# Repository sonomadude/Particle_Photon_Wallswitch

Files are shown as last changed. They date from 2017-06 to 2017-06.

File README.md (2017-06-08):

# Particle_Photon_Wallswitch
This repository will hold all assets for my entry into the Hackaday prize 2017 - a Particle Photon WallSwitch.

The goal of this project is to create a wall switch assembly that can fit into a deep US junction box, and, since it is using mains power directly, to do this safely (I will be installing a number of these in my barn, and eventually home if all goes well, so it has to be safe). And the switch must be both locally and remotely controllable.

On the safety end, great care is being taken in PCB layout to insure safe and reliable operation. The Saturn PCB Design Toolkit and PCB layout DRC (Design Rule Checking) was used to make sure trace separations met requirements for safety.  Board slots were also cut underneath the flyback transformer and the relay, separating the mains or 170VDC PCB areas from the nearby 5VDC areas. The assembly includes a fused resistor at power entry (that hopefully never blows because it cannot be reset) in case of a catastrophic failure of the 120VAC to 5VDC circuitry. All ingress wires are clamped to the PCB board for strain relief. If there is time, a probably oversimplified and probably crude EMC pre-compliance test will be done in my lab. 

There will be 5 ways to control the switch.  The first, physically making it switch, is done via a capacitive touch button. That button can be off or illuminated dimly when the switch is off, and then illuminated brightly when the switch is on (brightness controlled via PWM). To control the light remotely, an Android app, an iPhone app, an Alexa skill, and a web page will be created.

The firmware in the Particle Photon will initially just be able to turn on and off the switch. In final form, that firmware will be able to programmatically turn the switch on and off, either through specified times, or based on sunset or sunrise. The firmware will include the ability to identify time zone, DST, and sunrise/sunset using the Particle Cloud’s Webhooks capability.

The remote app software will also initially just be for turn on and turn off. But the finished apps will be able to set the time-based scheduling methods mentioned in the firmware paragraph above.  In addition, they will also be able to arrange multiple light switches into groups, and control those groups in the same manner – on/off, scheduled times, times based on sunrise/sunset.  A status display showing each of the lights is hoped to be part of this project.

If possible and not too over-ambitious, detailed documentation and videos will be created. 

I doubt there will be time but in an ideal world, a comparison of the cost to manufacture this unit in volume in China versus in the US in my lab would be great!  As currently designed and spec’d, this unit, if a real-world product, would be a complete fail - it is just too costly to make in the US.

I am hoping the ongoing project summary and the depth of the documentation will be of use to fellow developers and makers.  All IP of the project will be open source.

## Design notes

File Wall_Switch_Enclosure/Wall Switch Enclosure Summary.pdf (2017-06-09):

# Wall Switch Enclosure Summary

### (designed using Autodesk Inventor)

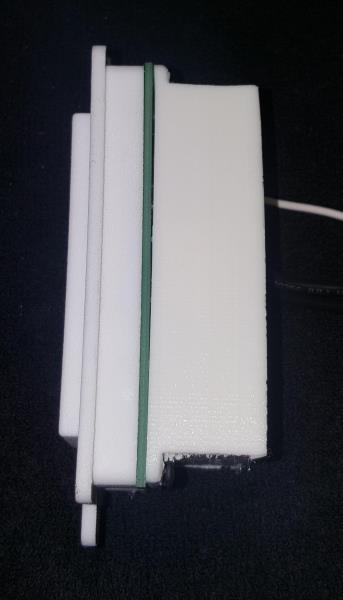
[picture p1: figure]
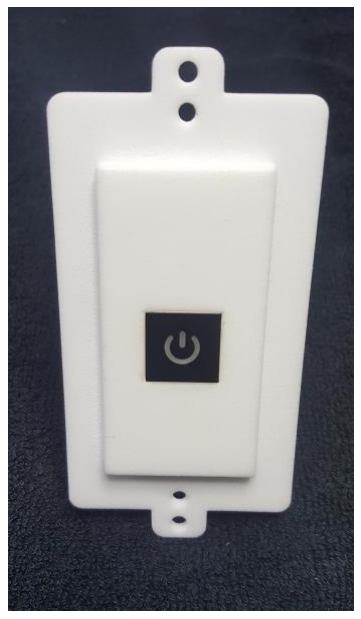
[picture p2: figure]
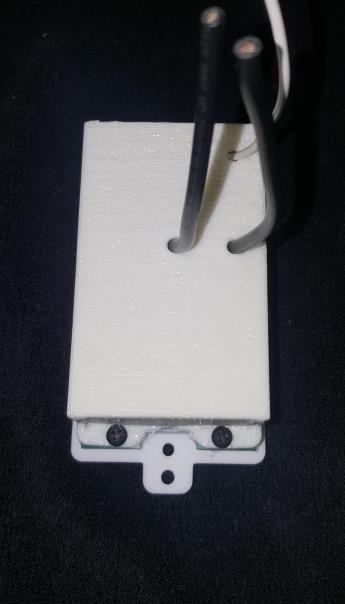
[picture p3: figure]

Prototype 3D Printed Enclosure (Middle shows off Shapeways quality)

The enclosure design includes a front piece with one side of the piece designed to fit inside a Decora switch plate, and the other side of the piece to match the dimensions of the PCB, including mounting holes, and fit within the interior walls of the junction box. The back piece is a cavity to enclose the PCB and associated components, and is to be screwed into the front piece at 4 locations with the PCB is sandwiched between the two. The back piece also has holes for wire egress from the enclosure – a 16 AWG 120VAC hot wire (to be black), a 120VAC 18 AWG neutral wire (to be white), and a 16 AWG 120VAC switched output wire (to be red).

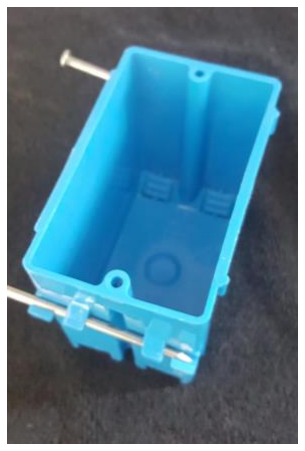
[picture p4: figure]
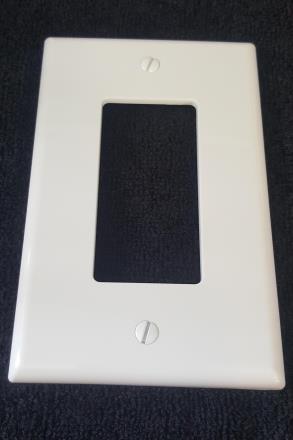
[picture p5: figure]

The design starts with the dimensions of a standard single gang US junction box, and the dimensions/shape of a rectangular hole in a Decora switch plate cover. Since the front piece must screw into the junction box, it was designed first. Simplifying the design, the following steps were taken:

Front Enclosure Piece
- Create a plate that will sit on the junction box, and screw into the junction box, with adequate thickness for strength. Include two holes on the plate for screwing into the junction box, and two holes for the Decora switch plate to be screwed to the Wall Switch.
- On one side of the plate, extrude a shape matching the X-Y-Z dimensions, and corner fillets to just fit into a Decora switch plate. Extrude a hole in the Decora extrusion to fit the capacitive touch button/display, and extend a border of that hole to the PCB (no way to even get a paper clip to the PCB that way).

- On the other side of that plate, extrude a shape that fits into the junction box with adequate clearance of the inside walls, and is tall enough to handle the height of the Particle Photon side of the PCB. Include holes in the wall of this extrusion that match the PCB’s mounting holes.
- Fillet as desired for smoothness of edges, reducing the amount of filament or resin that might be needed.

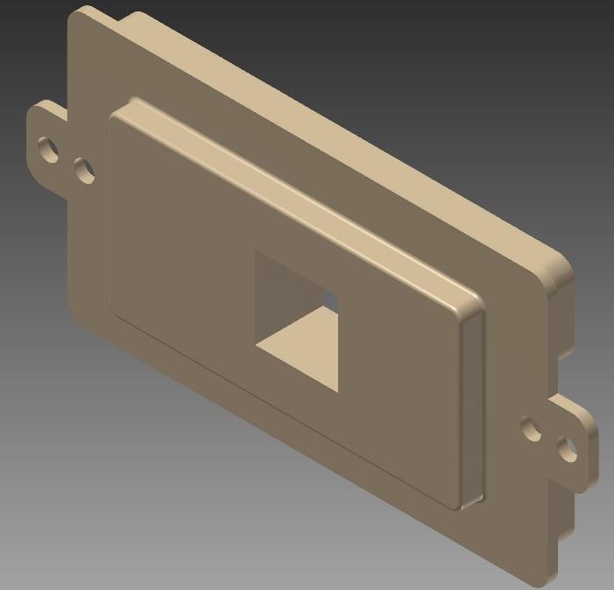
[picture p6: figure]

Back Enclosure Piece

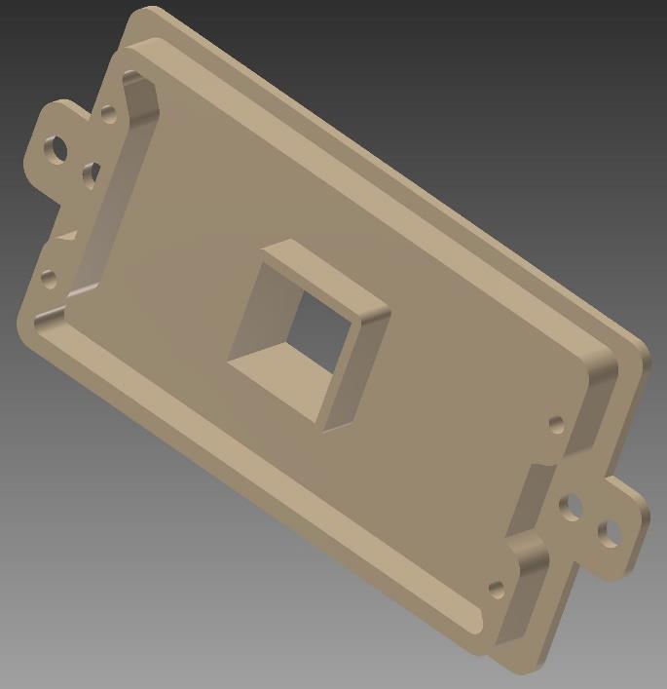
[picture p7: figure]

- Create a rectangular plate shape that will exactly match the size of the PCB and the junction-box side of the front part of enclosure. Include mounting holes so that the back plate can be bolted to the front enclosure piece, with the PCB sandwiched in the middle.
- On that plate, extrude a rectangular shape, hollowed in the middle, that has sufficient wall thickness for good strength, that is tall enough and to enclose the components on the back side of the PCB.
- Place a cover rectangular plate on that hollow rectangle with sufficient thickness for strength, and include 3 holes for wire ingress.
- Fillet as desired for smoothness of edges, reducing the amount of filament or resin that might be needed.

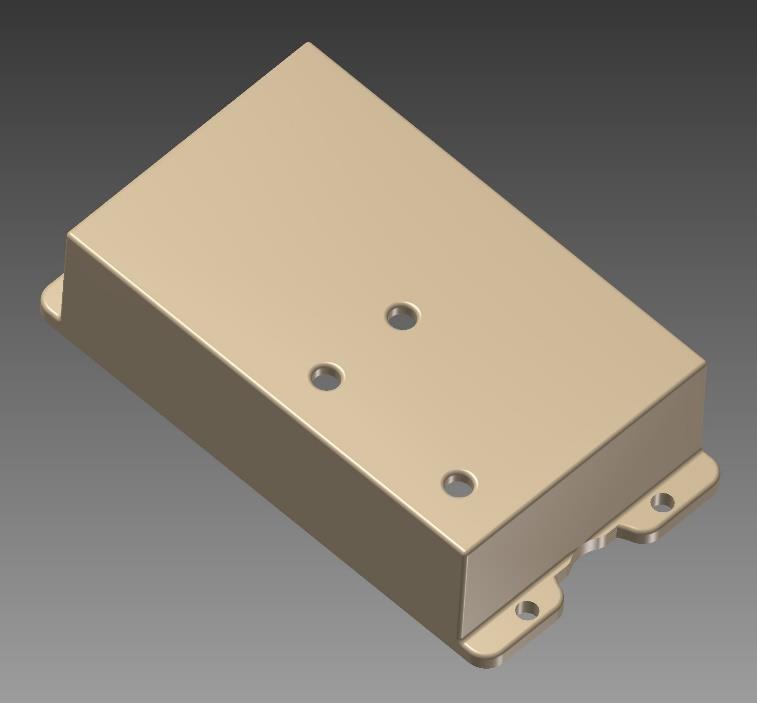
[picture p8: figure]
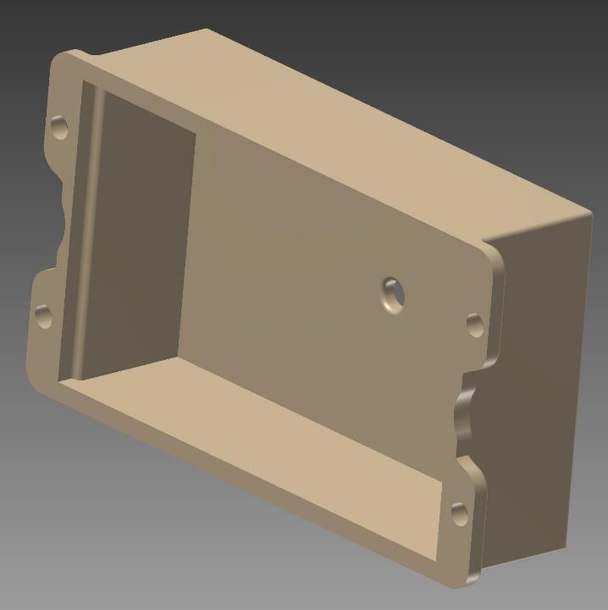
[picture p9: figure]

The front, because it is externally facing and is desired to be attractive, needs a fine white finish and it was expected that a run-of-the-mill 3D printer would be of too low a quality. That left 2 options. Go to Shapeways for a stellar but very expensive print ($30+ dollars just for the front), or a stereo-lithography printer like the one offered by Formlabs (which happens to be available at my local TechShop – about $13).

The back, because it is never seen, is to be printed on my Type A Machines Series 1 at minimal cost.

When printing the front on the Formlabs, the support structure created by the Formlabs slicer took some tinkering. If you printed with the job flat, you get unattractive dimples that couldn’t be easily removed. However, if you put the piece on angle, and had Formlabs generate the supports on the back of the piece, a very good print was obtained.

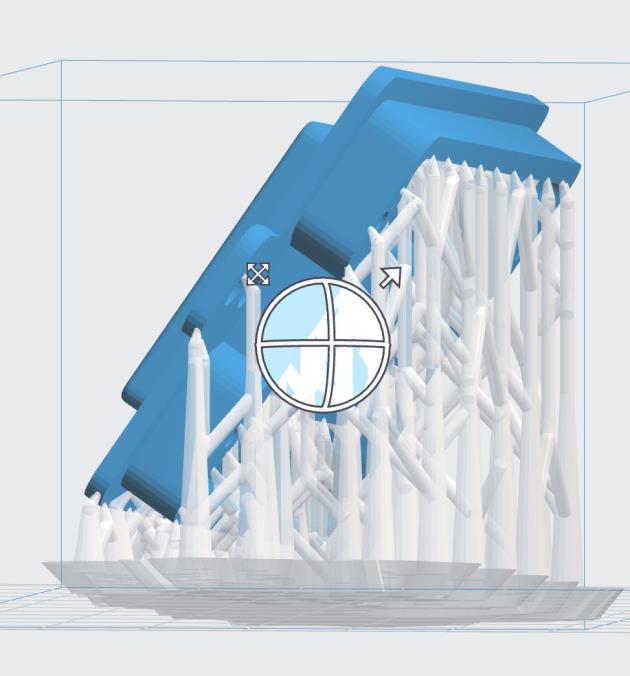
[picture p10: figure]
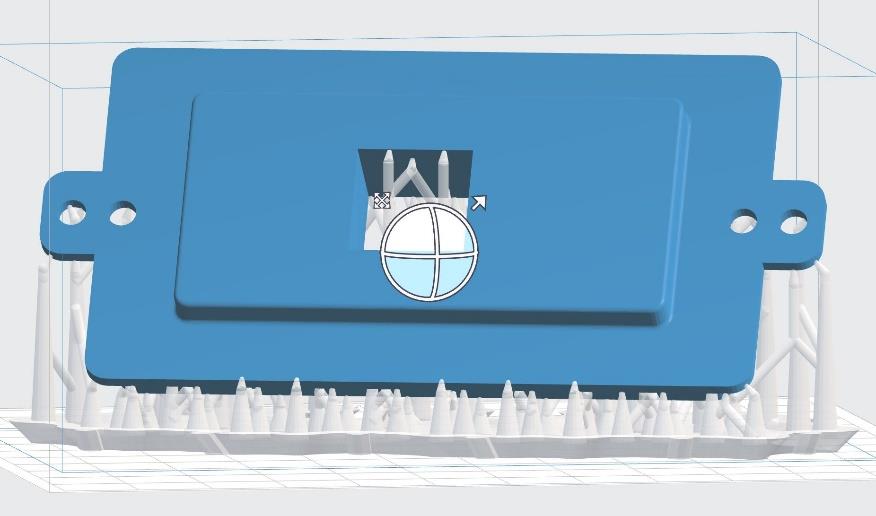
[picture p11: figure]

When printing the back on the Type A Series 1, the supports generated by the Cura slicer used with the machine did not do a good enough job. So, a support structure was added to the part in Autodesk Inventor. (The same was done for the front – designing a custom support for filament printing - but results were nowhere near as good as those on the Formlabs Form2).

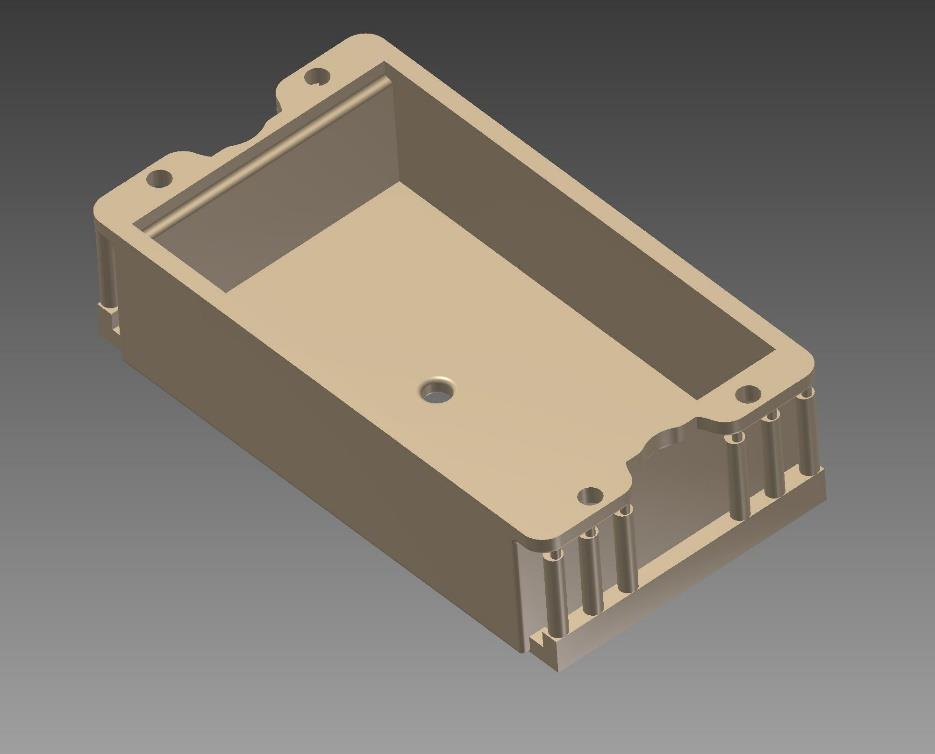
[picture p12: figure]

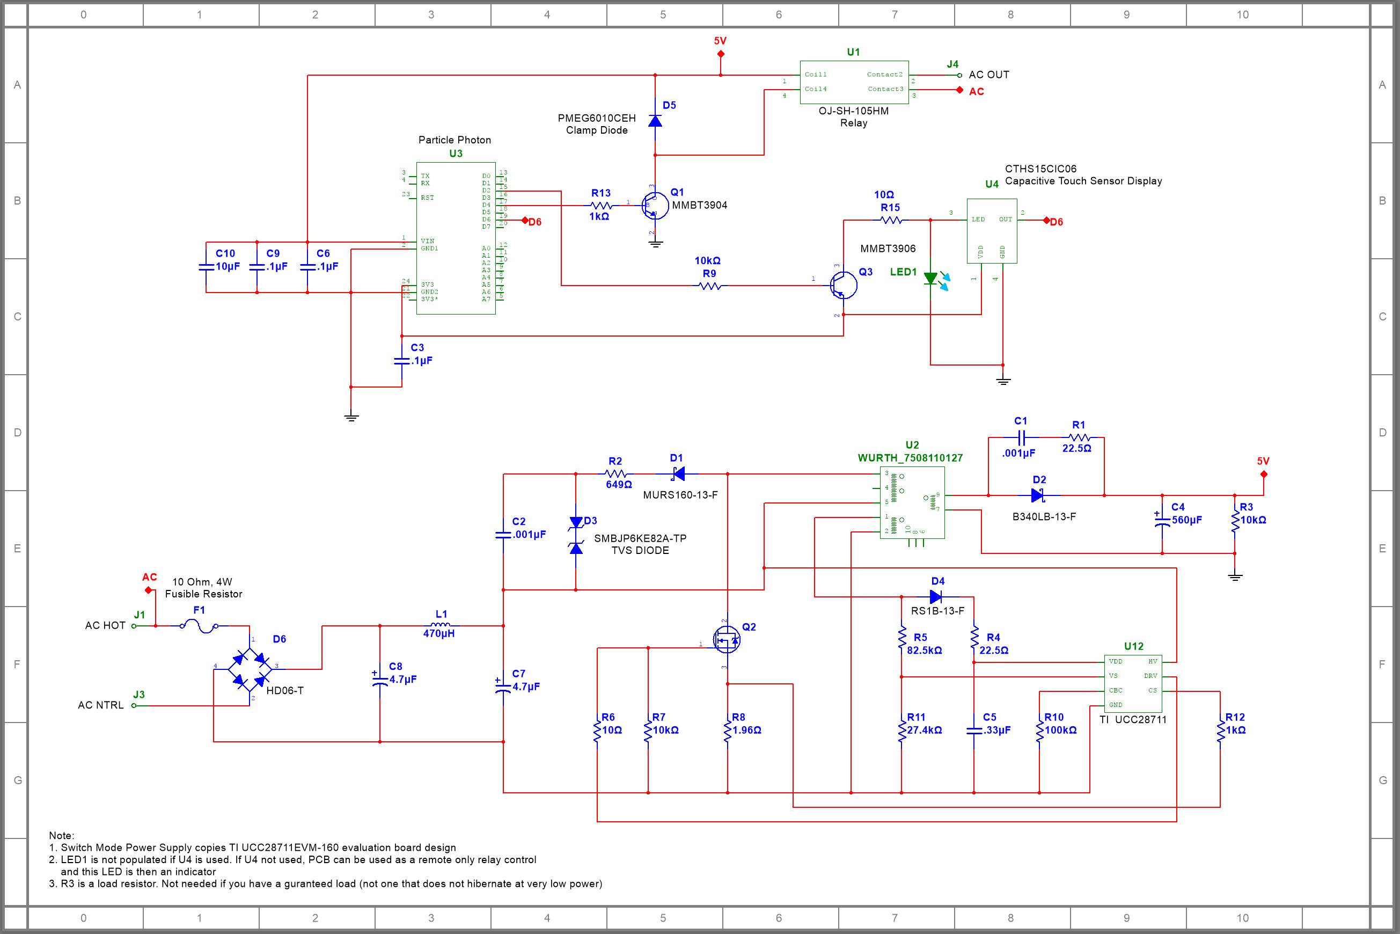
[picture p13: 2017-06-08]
LightSwitchSchematic.JPG

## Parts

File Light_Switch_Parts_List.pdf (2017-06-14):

# Photon Wallswitch Parts List and Finished Unit Cost Estimate

Below are the parts BOM for the PCB, the parts BOM for the enclosure, a stab at what it would cost to assemble and test a finished unit.

The PCB's and stencils were sourced through Elecrow, a very low cost supplier from Shenzhen. I get good quality PCBs from them.

The highest cost components: Particle Photon, capacitive touch switch, flyback transformer, the front facing plastic piece as that must be great quality (on Formlabs 2, the cost is $15.80 at my local TechShop - it would be $21.75 plus $5 shipping at Shapeways, and less than $1 with lower resolution filament printer), the PCB, and the cap-touch button/display).

Since these are for me, the assembly cost is my time for free obviously, so the relevant cost to me is about $75-80

If this were a business, there would be some cost allocation for the use of the "capital equipment" needed to build, assemble and test.
In my case that would solder station and reflow oven, 3D printer, and test bench equipment (scope, multimeters, etc).

PCB
Qty | Part | Part Number | Part Description | Detail | Qty 1 | Total | Qty 100 | Total | Qty 1000 | Total
1 | C1 | CL21B102KECSFNC (http://www.digikey.com/product-detail/en/CL21B102KECSFNC/1276-2431-1-ND/3890517) | 1nF, 50V, ceramic | 0805 | $ | 0.15 | $ | 0.15 | $ | 0.05 | $ | 0.05 | | $ | 0.03 | $ | 0.03
1 | C2 | C1206C102J2GACTU (http://www.digikey.com/product-detail/en/C1206C102J2GACTU/399-8130-1-ND/3471853) | 1nF, 200V, ceramic | 1206 | $ | 0.27 | $ | 0.27 | $ | 0.10 | $ | 0.10 | | $ | 0.06 | $ | 0.06
1 | C4 | EEU-FC1C561 (http://www.digikey.com/product-detail/en/EEU-FC1C561/P11202-ND/356106) | 560uF, 16V | Through Hole | $ | 0.70 | $ | 0.70 | $ | 0.33 | $ | 0.33 | | $ | 0.21 | $ | 0.21
1 | C5 | C2012X7R1H334K125AA (http://www.digikey.com/product-detail/en/C2012X7R1H334K125AA/445-7541-1-ND/2733613) | 330nF, 50V, Ceramic | 0805 | $ | 0.21 | $ | 0.21 | $ | 0.07 | $ | 0.07 | | $ | 0.04 | $ | 0.04
2 | C6. C9 | C0805C104K5RACTU (http://www.digikey.com/product-detail/en/C0805C104K5RACTU/399-1170-1-ND/411445) | .1uF, 50V, Ceramic | 0805 | $ | 0.10 | $ | 0.20 | $ | 0.02 | $ | 0.05 | | $ | 0.01 | $ | 0.03
2 | C7, C8 | UVC2G4R7MPD (http://www.digikey.com/product-detail/en/UVC2G4R7MPD/493-6681-ND/3664131) | 4.7uF 400V Electrolytic | Through Holse | $ | 0.74 | $ | 1.48 | $ | 0.35 | $ | 0.69 | | $ | 0.22 | $ | 0.44
1 | C3 | JMK212BBJ476MG-T (https://www.digikey.com/product-detail/en/taiyo-yuden/JMK212BBJ476MG-T/587-4280-1-ND/5344315) | 47uF, 6.3V, Ceramic | 0805 | $ | 0.38 | $ | 0.38 | $ | 0.16 | $ | 0.16 | | $ | 0.10 | $ | 0.10
1 | C10 | CC0805MKX5R8BB226 (https://www.digikey.com/product-detail/en/yageo/CC0805MKX5R8BB226/311-1903-1-ND/5195805) | 22uF, 25V, Ceramic | 0805 | $ | 0.83 | $ | 0.83 | $ | 0.42 | $ | 0.42 | | $ | 0.28 | $ | 0.28
1 | D1 | MURS160-13-F (http://www.digikey.com/product-detail/en/MURS160-13-F/MURS160-FDICT-ND/815906) | Diode, General Purpose, 600V, 1A | DO-214AA, SMB | $ | 0.45 | $ | 0.45 | $ | 0.24 | $ | 0.24 | | $ | 0.13 | $ | 0.13
1 | D2 | B340LB-13-F (http://www.digikey.com/product-detail/en/B340LB-13-F/B340LB-FDICT-ND/755495) | Schottkey Diode, 40V, 3A | DO-214AA, SMB | $ | 0.44 | $ | 0.44 | $ | 0.29 | $ | 0.29 | | $ | 0.17 | $ | 0.17
1 | D3 | SMBJP6KE82A-TPMSCT-ND (http://www.digikey.com/product-detail/en/SMBJP6KE82A-TP/SMBJP6KE82A-TPMSCT-ND/2345774) | TVS Diode Surge Suppressor | DO-214AA, SMB | $ | 0.46 | $ | 0.46 | $ | 0.25 | $ | 0.25 | | $ | 0.13 | $ | 0.13
1 | D4 | RS1B-13-F (http://www.digikey.com/product-detail/en/RS1B-13-F/RS1B-FDICT-ND/717915) | Diode General Purpose, 100v, 1A | DO-214AC, SMA | $ | 0.49 | $ | 0.49 | $ | 0.21 | $ | 0.21 | | $ | 0.10 | $ | 0.10
1 | D5 | PMEG6010CEH,115 (https://www.digikey.com/product-detail/en/nxp-semiconductors/PMEG6010CEH,115/568-4104-1-ND/1589917) | Schottkey Diode, 60V, 1A | SOD123F | $ | 0.40 | $ | 0.40 | $ | 0.22 | $ | 0.22 | | $ | 0.12 | $ | 0.12
1 | D6 | HD06-T (http://www.digikey.com/product-detail/en/HD06-T/HD06DIDKR-ND/1837813) | Bridge Rectifier 600V, 800mA | 4-SMD, Gull Wing | $ | 0.53 | $ | 0.53 | $ | 0.29 | $ | 0.29 | | $ | 0.16 | $ | 0.16
1 | L1 | RLB0608-471KL (http://www.digikey.com/product-search/en?WT.z_header=search_go&lang=en&site=us&x=0&y=0&formaction=on) | Inductor, 470uH | Through Hole | $ | 0.25 | $ | 0.25 | $ | 0.15 | $ | 0.15 | | $ | 0.10 | $ | 0.10
1 | Q1 | MMBT3904 (http://www.digikey.com/product-detail/en/MMBT3904-7-F/MMBT3904-FDICT-ND/815727) | 2N3904 NPN Transistor | SOT23 | $ | 0.13 | $ | 0.13 | $ | 0.06 | $ | 0.06 | | $ | 0.03 | $ | 0.03
1 | Q2 | STD2HNK60Z-1 (http://www.digikey.com/product-search/en?WT.z_header=search_go&lang=en&site=us&x=0&y=0&formaction=on) | MOSFET, N-Channel, 600V, 2A | Throigh Hole I-Pak | $ | 1.30 | $ | 1.30 | $ | 0.90 | $ | 0.90 | | $ | 0.59 | $ | 0.59
1 | Q3 | MMBT3906 (https://www.digikey.com/product-detail/en/on-semiconductor/MMBT3906LT1G/MMBT3906LT1GOSCT-ND/1139817) | 2N3906 | SOT23 | $ | 0.11 | $ | 0.11 | $ | 0.06 | $ | 0.06 | | $ | 0.02 | $ | 0.02
1 | R2 | ERJ-6ENF6490V (http://www.digikey.com/product-detail/en/ERJ-6ENF6490V/P649CCT-ND/118903) | 649 Ohm, 1/18W, 0805, 1% | 0805 | $ | 0.10 | $ | 0.10 | $ | 0.02 | $ | 0.02 | | $ | 0.01 | $ | 0.01
2 | R1, R4 | ERJ-6ENF22R6V (http://www.digikey.com/product-detail/en/ERJ-6ENF22R6V/P22.6CCT-ND/118481) | 22.5 Ohm, 1/18W, 0805, 1% | 0805 | $ | 0.10 | $ | 0.20 | $ | 0.02 | $ | 0.03 | | $ | 0.01 | $ | 0.01
1 | R5 | ERJ-6ENF8252V (http://www.digikey.com/product-detail/en/ERJ-6ENF8252V/P82.5KCCT-ND/119527) | 82.5K, 1/8 Watt, 0805 1% | 0805 | $ | 0.10 | $ | 0.10 | $ | 0.02 | $ | 0.02 | | $ | 0.01 | $ | 0.01
2 | R6,R15 | ERJ-6ENF10R0V (http://www.digikey.com/product-detail/en/ERJ-6ENF10R0V/P10.0CCT-ND/118378) | 10 Ohm, 1/8W, 0805, 1% | 0805 | $ | 0.10 | $ | 0.20 | $ | 0.02 | $ | 0.03 | | $ | 0.01 | $ | 0.01
2 | R3, R7 | ERJ-6GEYJ103V (http://www.digikey.com/product-detail/en/ERJ-6GEYJ103V/P10KACT-ND/43118) | 10K Ohm, 1/8W, 0805, 1% | 0805 | $ | 0.10 | $ | 0.20 | $ | 0.02 | $ | 0.03 | | $ | 0.01 | $ | 0.01
2 | R12,R13 | ERJ-6GEYJ102V (http://www.digikey.com/product-detail/en/ERJ-6GEYJ102V/P1.0KACT-ND/42833) | 1K Ohm, 1/8W, 0805, 1% | 0805 | $ | 0.10 | $ | 0.20 | $ | 0.02 | $ | 0.03 | | $ | 0.01 | $ | 0.01
1 | U4 | CTHS15CIC06ONOFF (https://www.digikey.com/product-detail/en/visual-communications-company-vcc/CTHS15CIC06ONOFF/CTHS15CIC06ONOFF-ND/6556990) | Switch, Push, Capacitive, Illuminated | Custom | $ | 7.31 | $ | 7.31 | $ | 4.41 | $ | 4.41 | | $ | 3.67 | $ | 3.67
1 | R8 | RC1206FR-071R96L (http://www.digikey.com/product-detail/en/RC1206FR-071R96L/311-1.96FRCT-ND/731426) | 1.96 Ohm, 1/4W | 1206 | $ | 0.10 | $ | 0.10 | $ | 0.02 | $ | 0.02 | | $ | 0.01 | $ | 0.01
1 | R10 | NTCS0805E3104JXT (http://www.digikey.com/product-detail/en/NTCS0805E3104JXT/BC2566CT-ND/2237403) | NTC Thermistor, 100k Ohm, 0805 | 0805 | $ | 0.55 | $ | 0.55 | $ | 0.28 | $ | 0.28 | | $ | 0.22 | $ | 0.22
1 | R11 | ERA-6AEB2742V (http://www.digikey.com/product-detail/en/ERA-6AEB2742V/P27.4KDACT-ND/3075060) | 27.4K Ohm, 1/8W, 0805, 1% | 0805 | $ | 0.36 | $ | 0.36 | $ | 0.12 | $ | 0.12 | | $ | 0.01 | $ | 0.01
1 | U1 | UCC28711D (https://www.digikey.com/product-detail/en/texas-instruments/UCC28711D/296-35536-5-ND/3767613) | TI Flyback PWM Controller | 8-SOIC (7 leads) | $ | 1.50 | $ | 1.50 | $ | 1.04 | $ | 1.04 | | $ | 0.68 | $ | 0.68
1 | F1 | SP3AJT10R0 (https://www.digikey.com/product-detail/en/stackpole-electronics-inc/SP3AJT10R0/SP3AJT10R0CT-ND/2665477) | Resistor, fusible power, 4W, 10 Ohm | Through Hole | $ | 0.55 | $ | 0.55 | $ | 0.31 | $ | 0.31 | | $ | 0.22 | $ | 0.22
1 | U3 | Particle Photon (https://store.particle.io/collections/photon) | Photon, No Headers | Surface Mount | $ | 19.00 | $ | 19.00 | $ | 13.00 | $ | 13.00 | ??? | $ | 11.00 | $ | 11.00
1 | RLY1 | OJ-SH-105HM,000 (https://www.digikey.com/product-detail/en/te-connectivity-potter-brumfield-relays/OJ-SH-105HM,000/PB2004-ND/1427485) | 10A 5VDC Relay | Through Hole | $ | 1.75 | $ | 1.75 | $ | 1.31 | $ | 1.31 | | $ | 1.02 | $ | 1.02
1 | T1 | 7508110127 (http://katalog.we-online.de/en/icref/UCC28711-Rev-B_Flyback_1?m=n) | WurthFlyback Transformer | Through Hole, 10 pins | $ | 2.56 | $ | 2.56 | $ | 2.56 | $ | 2.56 | | $ | 2.00 | $ | 2.00
1 | PCB | NA | Sourced from Elecrow | 10 PCBs @ $11.50 + $15 Ship | $ | 2.65 | $ | 2.65 | $ | 1.00 | $ | 1.00 | | $ | 0.50 | $ | 0.50
Subtotal | $ | 46.11 | Subtotal | $ | 28.75 | Subtotal | $ | 22.15

Enclosure/Other
4 | Hardware | 90935A133 (http://www.mcmaster.com/#90935a133/=vvyiu9) | #4, 3/8" screws | To bolt front & back shells | $ | 0.04 | $ | 0.16 | $ | 0.04 | $ | 0.16 | $ | 0.02 $ | 0.08
1 | 3D print | Various Sources | Back Shell | Any old 3D printer | $ | 1.00 | $ | 3.00 | $ | 1.00 | $ | 1.00 | $ | 0.05 $ | 0.05
1 | 3D print | Various Sources | Front Shell | Form2 3D printer (TechShop) | $ | 15.80 | $ | 15.80 | $ | 15.80 | $ | 15.80 | $ | 6.00 $ | 6.00
2 | Wire | Various Sources | Black 16 AWG | 8-10" length | $ | 0.20 | $ | 0.40 | $ | 0.20 | $ | 0.40 | $ | 0.10 $ | 0.20
1 | Wire | Various Sources | White 18 AWG | 8-10" length | $ | 0.20 | $ | 0.20 | $ | 0.20 | $ | 0.20 | $ | 0.10 $ | 0.10
1 | Wire | Various Sources | Green 18 AWG | 8-10" length | $ | 0.20 | $ | 0.20 | $ | 0.20 | $ | 0.20 | $ | 0.10 $ | 0.10
1 | Clamp | Various Sources | P-clamp, strain relief | 3/8" opening | $ | 0.15 | $ | 0.15 | $ | 0.15 | $ | 0.15 | $ | 0.05 $ | 0.05
1 | Hardware | Various Sources | #6 screw, nut, lock washer | To bolt down strain P-clamp | $ | 0.20 | $ | 0.20 | $ | 0.20 | $ | 0.20 | $ | 0.10 $ | 0.10
1 | Packaging | Various Sources | Cardboard box, user guide | Wild guess | $ | 0.75 | $ | 0.75 | $ | 0.75 | $ | 0.75 | $ | 0.50 $ | 0.50
Subtotal | $ | 20.86 | Subtotal | $ | 18.86 | $ | 7.18
| | | | | Total | | $ | 66.97 | Total | | $ | 47.61 | | Total | | $ | 29.33
CA Tax | $ | 6.03 | CA Tax/Brd | $ | 5.79 | CA Tax | $ | -
Ship Est.* | $ | 10.00 | Ship Est.* | $ | 0.30 | Ship Est.* | $ | 0.10
Total BOM | $ | 83.00 | Total | $ | 53.70 | Total | $ | 29.43
Shipping total estimated at $30. | Shipping total estimated at $100.
Assembly Test Costs - Quantity 1
Time | Job Description | | | | | | | | | Rate | | Total
1 | Solder Paste, Solder, Flux | $ | 0.20 | $ | 0.20
40 | Sort SMD parts, squeegee paste, place parts on PCB by hand, and reflow (Actual time per board, 2 boards made) | $ | 20.00 | $ | 13.33
10 | Through hole parts sort, insert in board, solder (took 8-10 minutes) | $ | 20.00 | $ | 3.33
15 | Test the board (Assumes this takes average of 15 minutes) | $ | 20.00 | $ | 5.00
20 | 3D print front/back plastic enclosure pieces (Assumed 20 minutes to start print/clean it (especially Form 2 Resin) | $ | 20.00 | $ | 6.67
10 | (assumed 10 minutes) | $ | 20.00 | $ | 3.33
Subtotal | $ | 31.67
Total Cost $ | 98.64 | Total Cost | $ | 79.27

Manufacturing, One Time Cost
1 | NA | NA | Stencil, 30mm x40mm frame | Elecrow, $18 plus $15 shipping | $ | 33.00 | $ | 33.00

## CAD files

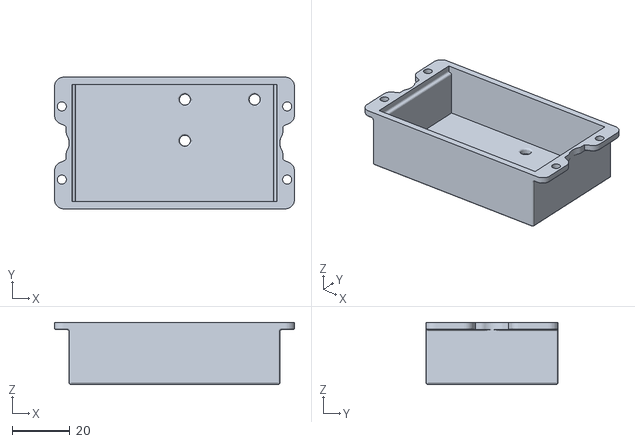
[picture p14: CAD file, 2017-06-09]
Wall_Switch_Enclosure/Wall_Switch_June_8_2017_Back.stl
83.3 x 45.7 x 21.6

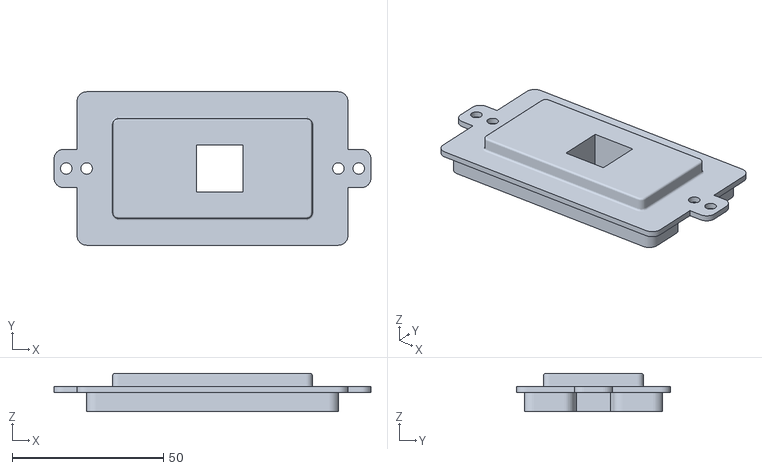
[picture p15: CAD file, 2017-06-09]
Wall_Switch_Enclosure/Wall_Switch_June_8_2017_Front._Sppt.stl
104.9 x 50.8 x 12.7

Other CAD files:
Wall_Switch_Enclosure/Wall_Switch_June_8_2017_Back.ipt
Wall_Switch_Enclosure/Wall_Switch_June_8_2017_Front._Sppt.ipt

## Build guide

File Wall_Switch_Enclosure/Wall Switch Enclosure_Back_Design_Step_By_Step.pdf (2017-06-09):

## Wall Switch Enclosure: Summarized Step-By-Step 3D Model

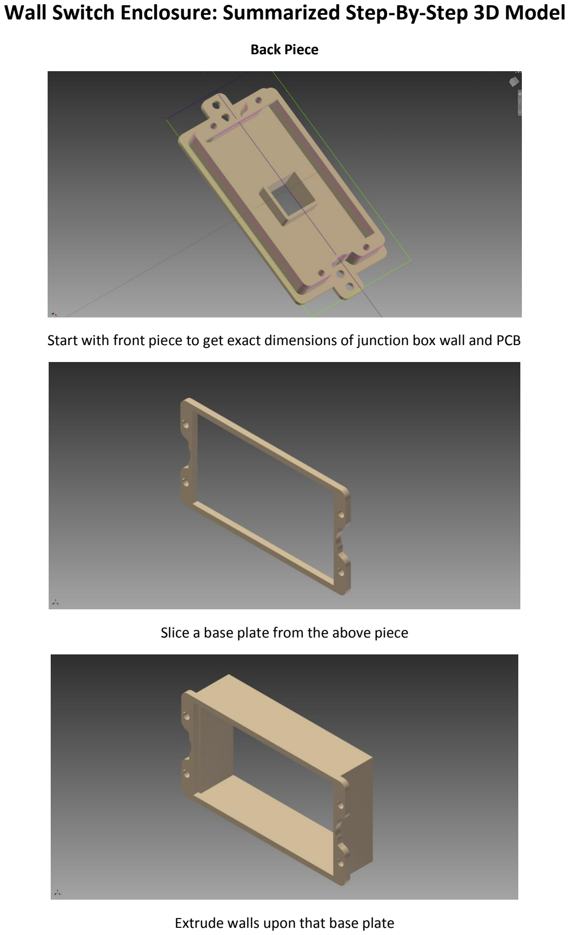
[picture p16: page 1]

Back Piece

Start with front piece to get exact dimensions of junction box wall and PCB

Slice a base plate from the above piece

Extrude walls upon that base plate

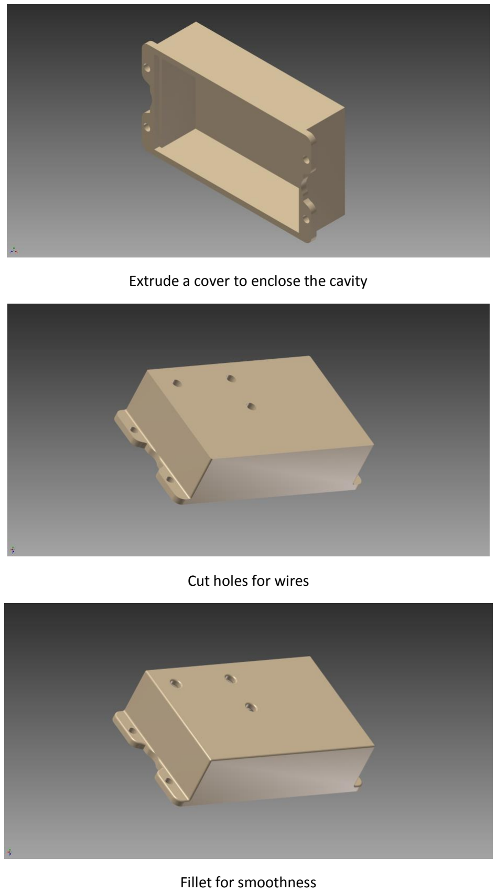
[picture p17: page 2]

Extrude a cover to enclose the cavity

Cut holes for wires

Fillet for smoothness

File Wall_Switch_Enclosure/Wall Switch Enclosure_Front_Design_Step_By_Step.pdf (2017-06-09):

## Wall Switch Enclosure: Summarized Step-By-Step 3D Model

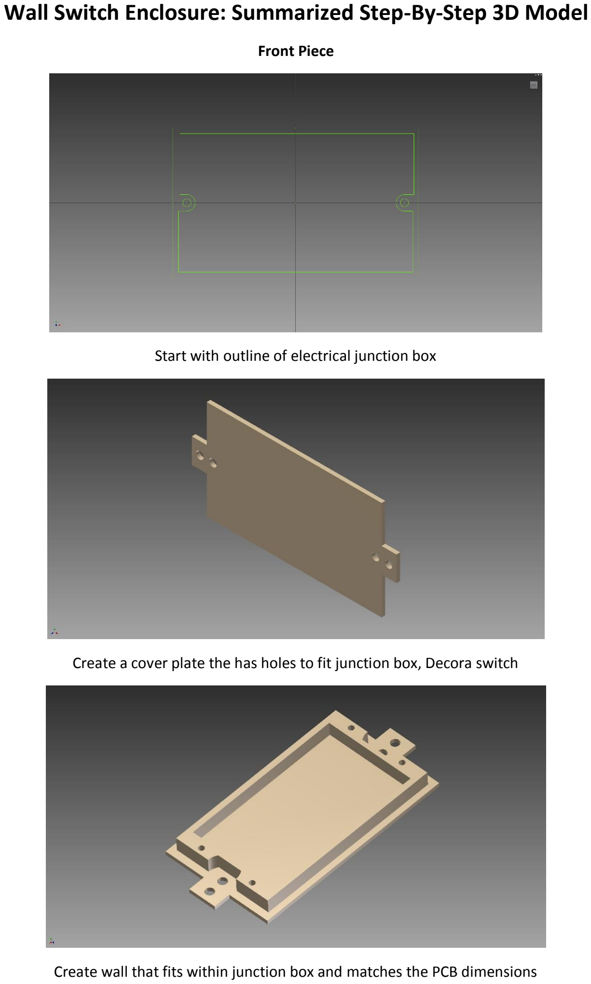
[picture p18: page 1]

Front Piece

Start with outline of electrical junction box

Create a cover plate the has holes to fit junction box, Decora switch

Create wall that fits within junction box and matches the PCB dimensions

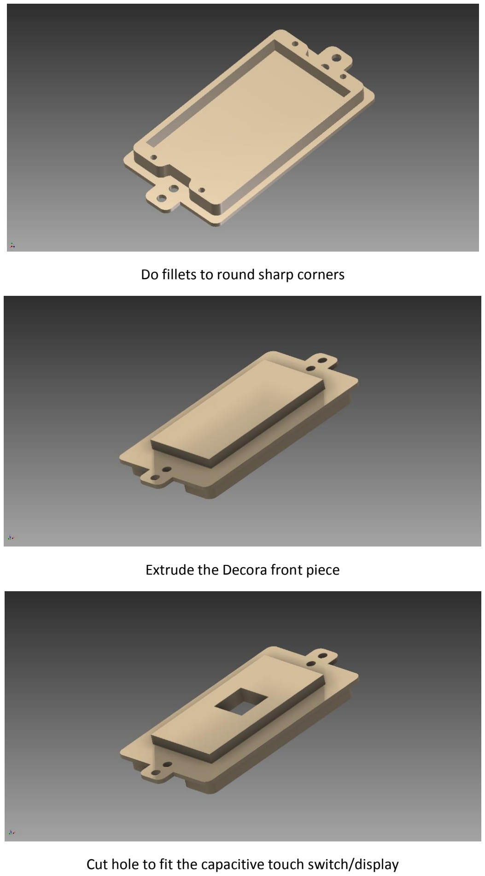
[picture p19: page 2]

Do fillets to round sharp corners

Extrude the Decora front piece

Cut hole to fit the capacitive touch switch/display

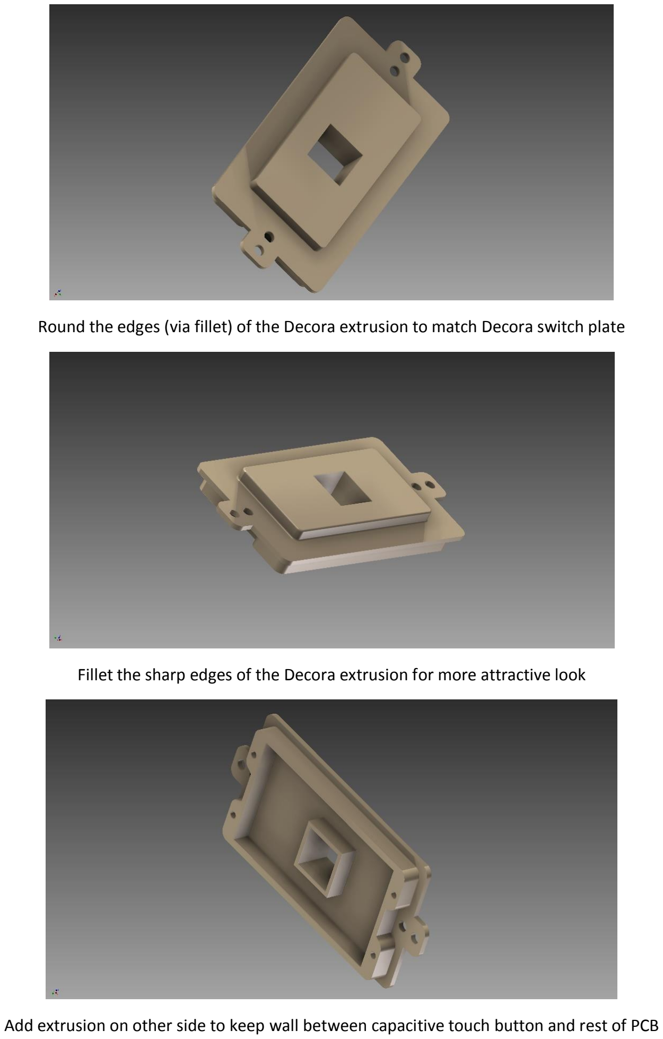
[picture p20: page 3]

Round the edges (via fillet) of the Decora extrusion to match Decora switch plate

Fillet the sharp edges of the Decora extrusion for more attractive look

Add extrusion on other side to keep wall between capacitive touch button and rest of PCB

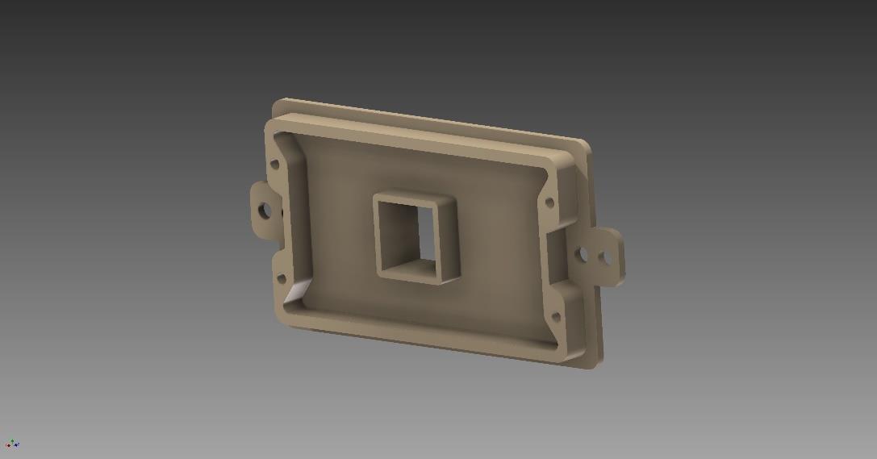
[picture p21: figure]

Carve out excess wall fill at corners to reduce filament needed

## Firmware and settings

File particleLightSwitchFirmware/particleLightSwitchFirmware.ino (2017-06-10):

// This code is simple - it is just for prototype testing. Evenutally
// this code will include the ability to have scheduled on/off times,
// account for DST, will be able to use sunrise/sunset knowledge so
// lights can control themselves

int capDisplay = D2;    // Drives LED of cap touch switch/display
int relayDrive = D4;    // Drives relay controlling 120VAC
int capSense = D6;      // Senses touch on cap touch button

int lightState = 0;     // State variable for relay status

void setup()
{
// Setup pins
    pinMode(relayDrive, OUTPUT);
    pinMode(capDisplay, OUTPUT);
    pinMode(capSense, INPUT);
    digitalWrite(relayDrive, LOW);    // Set initial state of relay open
    digitalWrite(capDisplay, HIGH);   // Set initial state of LED off

// Set Particle variable and function
    Particle.variable("lightState", lightState);   // variable: 0 = Off, 1 = On
    Particle.function("switchLight", switchLight); // Sets relayState
}


void loop()
{
// Test cap touch sensor for physical finger touch
  if (digitalRead(capSense) == 1 && lightState == 0) {      // If relay off & touch sensed
    delay(25);                                              // Is it really touched? Wait ...
    if (digitalRead(capSense) == 1) lightState = 1;         // .... turn it on
    setOutputs();                                           // Switch relay
    delay(1000);                                            // Insure no double touch
  }
  else if (digitalRead(capSense) == 1 && lightState == 1) { // else if relay is on ...
    delay(25);                                              // Is it really touched? Wait ...
    if (digitalRead(capSense) == 1) lightState = 0;         // ... turn it off
    setOutputs();                                           // Set LED and relay output pins
    delay(1000);                                            // Insure no double touch
  }
}


// Function to switch relay, turn on/off LED in display
void setOutputs()
{
    if (lightState == 0)                    // Need to set relay open
    {
        digitalWrite(relayDrive, LOW);      // Switch relay off
        digitalWrite(capDisplay, HIGH);     // Turn off PCB LED
    }
    else if (lightState == 1)               // Need to pull in relay
    {
        digitalWrite(relayDrive, HIGH);     // Switch relay on
        digitalWrite(capDisplay, LOW);      // Turn on PCB LED
    }
}


// PARTICLE FUNCTION switchRelay
int switchLight(String x)               // String x will be a 0 for relay off; a 1 for relay on)
{
    int tempValue = x.charAt(0) - '0';  // Extract integer
    if (tempValue == 0)
    {
        lightState = 0;                  // Set for relay off
    }
    else if (tempValue == 1)
    {
       lightState = 1;                   // Set for relay on
    }
    setOutputs();                        // Set LED and relay output pins
    return lightState;
}

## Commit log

2017-06-10 Add files via upload
    This is the "Simple" prototype firmware in use for testing Android App to/from Photon communication
2017-06-10 Add files via upload
    These are the prototype files for the Wall Switch Alexa skill. The lambda JavaScript function works and while the Intents and utterances also work for test purposes, they are not quite ready nor correct for use with a real Alexa.
2017-06-11 Add files via upload
    Prototype iOS app that does simple turn on, turn off and refresh status to Particle Photon loaded with particleLightSwitchFirmware avaialble on this site. (YOu will need to add your Photon ID and you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
2017-06-15 Add files via upload
    These files are updated and believed to be working. They communicate with the Particle Photon firmware also available on this site.
    The Photon IDs and access Token have been banked out - you will need to insert yours.
